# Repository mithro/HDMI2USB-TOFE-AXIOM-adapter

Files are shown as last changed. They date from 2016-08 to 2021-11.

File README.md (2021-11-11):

# TOFE to AXIOM Adapter

This repository contains a board for adapting the
[TOFE interface](https://tofe.io/) to the interface used by the
[plugin modules for the AXIOM Beta](https://wiki.apertus.org/index.php/AXIOM_Beta/AXIOM_Beta_Hardware#Plugin_Modules).

These adapter boards are **transparent** to the TOFE bus and have identical
schematics, only the PCB design differs.

Any **passive** PCI-Express adapter or riser which meets the PCI-Express
specification should be also compatible with the TOFE interface (but the
reverse is not necessarily true).

For more information on;
 * [The TOFE interface, see the HDMI2USB website](http://hdmi2usb.tv/tofe).
 * [The AXIOM interface, see the AXIOM wiki](https://wiki.apertus.org/index.php/AXIOM_Beta)
 * KiCad software, see [KiCad website](http://kicad.org/).

## Editing

Download with
```
git clone git+ssh://git@github.com/mithro/HDMI2USB-TOFE-AXIOM-Adapter.git --recursive
```

The designs in this repository was made using [KiCad](http://www.kicad.org/)
version **4.0.2 BZR 6225**
([the current stable version of KiCad](http://kicad.org/download/)).

## License

This work is copyright TimVideos.us Developers 2015 and licensed under a
Creative Commons Attribution-ShareAlike 4.0 International License.

You should have received a copy of the license along with this
work.  If not, see <http://creativecommons.org/licenses/by-sa/4.0/>.



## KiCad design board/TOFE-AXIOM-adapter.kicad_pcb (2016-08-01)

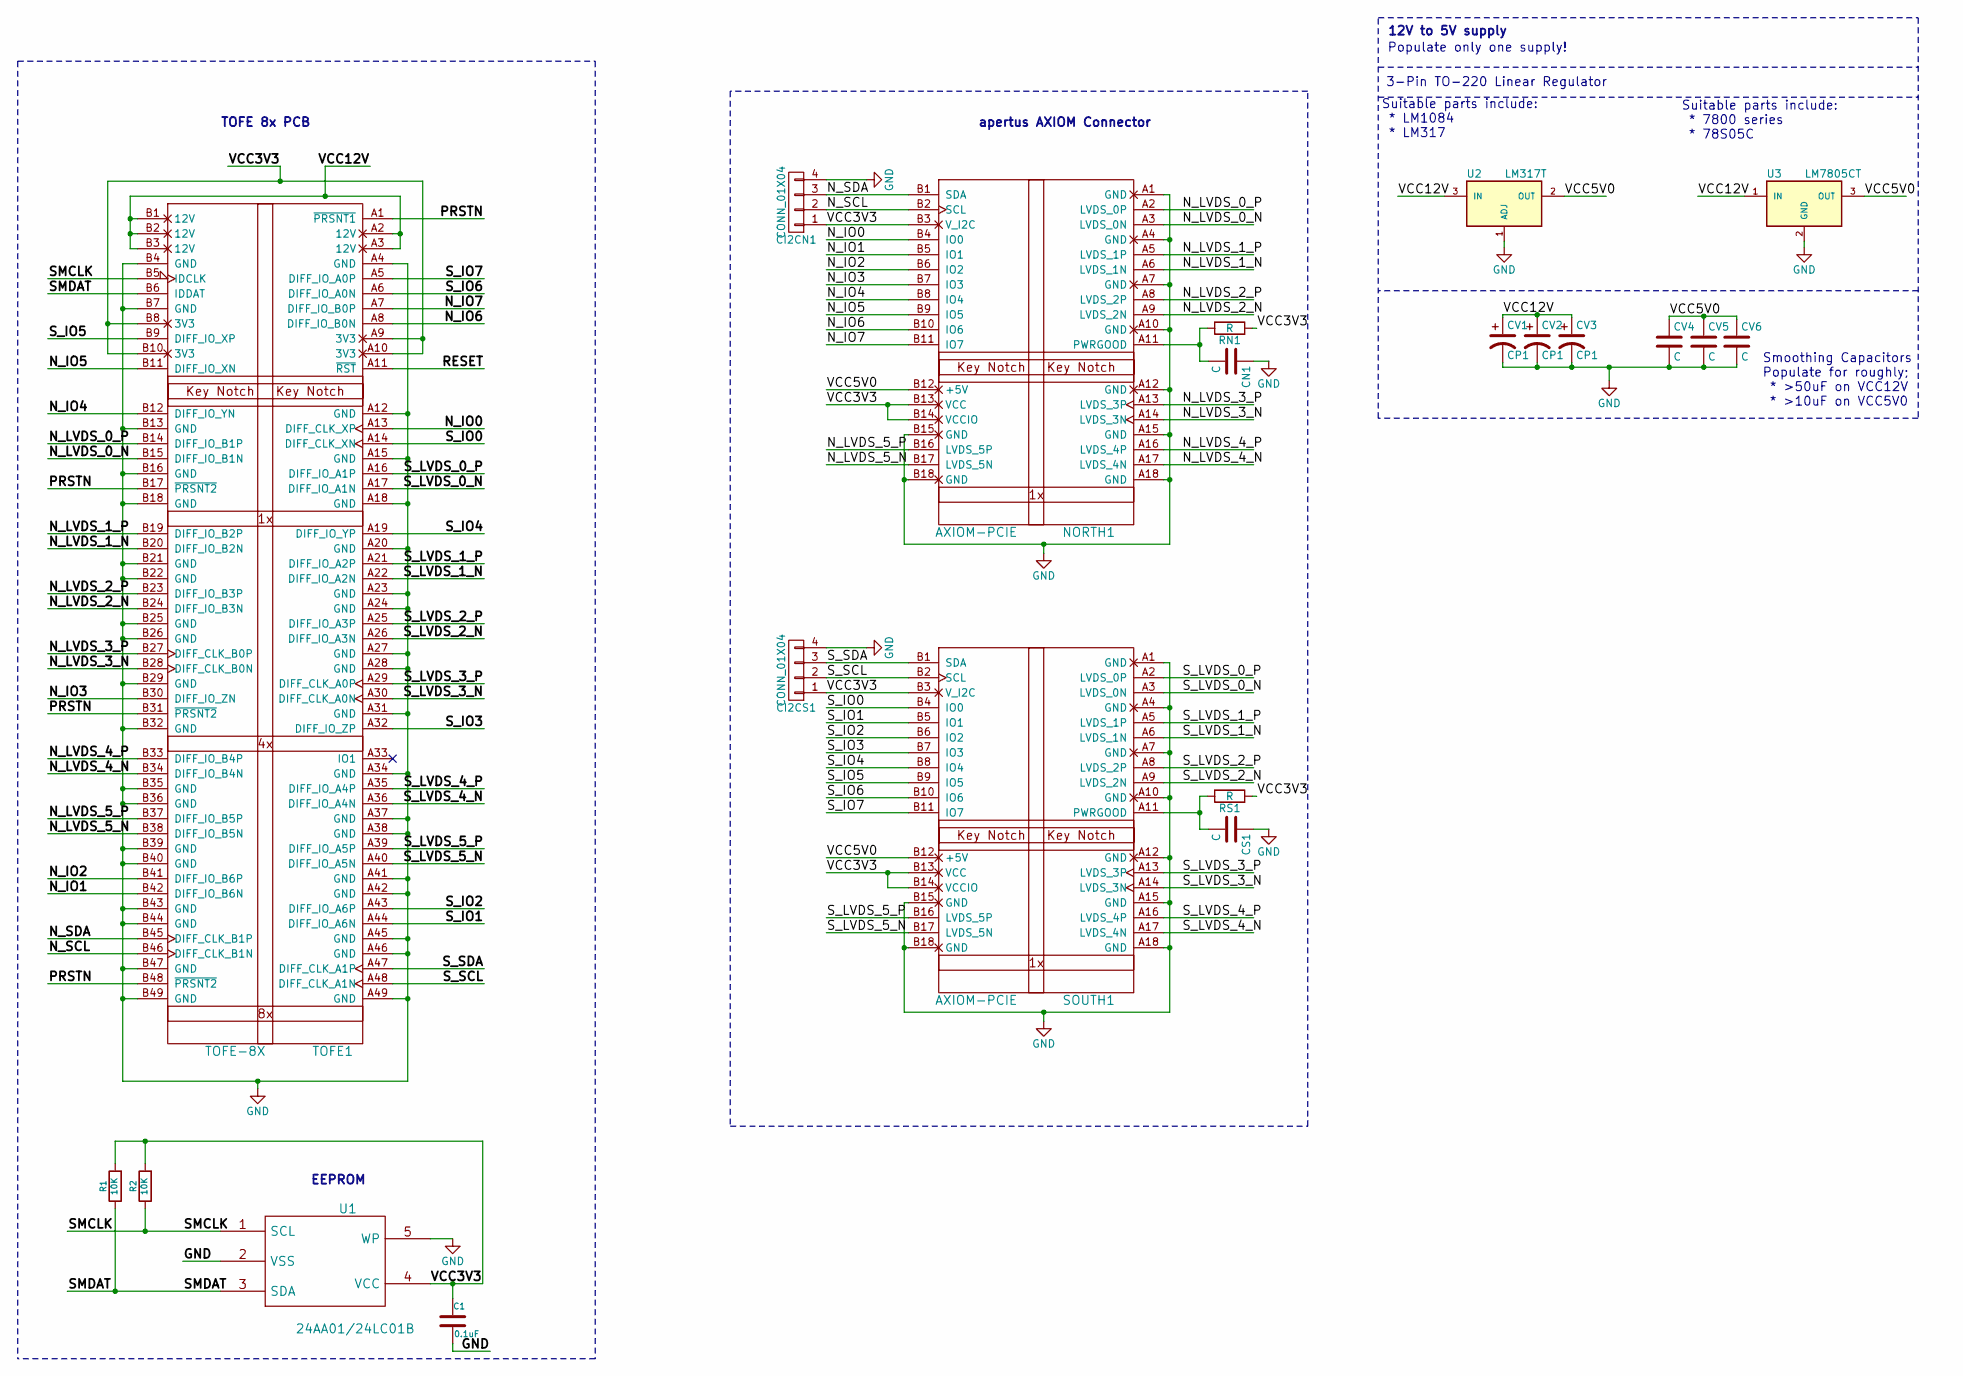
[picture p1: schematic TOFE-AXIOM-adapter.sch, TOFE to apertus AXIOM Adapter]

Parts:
C1: 0.1uF; C_1206_HandSoldering
CI2CN1, CI2CS1: CONN_01X04; Pin_Header_Straight_1x04
CN1: C; C_1206_HandSoldering
CS1: C; C_1206_HandSoldering
CV1, CV2, CV3: CP1; SMD-1206_Pol
CV4, CV5, CV6: C; C_1206_HandSoldering
NORTH1: AXIOM-PCIE; pci-x_conn-x1
R1, R2: 10K; R_0603_HandSoldering
RN1: R; R_0603_HandSoldering
RS1: R; R_0603_HandSoldering
SOUTH1: AXIOM-PCIE; pci-x_conn-x1
TOFE1: TOFE-8X; TOFE_8X_Pins
U1: 24AA01/24LC01B; SOT-23-5
U2: LM317T
U3: LM7805CT

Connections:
/N_IO0: NORTH1.B4 (IO0), TOFE1.A13 (DIFF_CLK_XP)
/N_IO1: NORTH1.B5 (IO1), TOFE1.B42 (DIFF_IO_B6N)
/N_IO2: NORTH1.B6 (IO2), TOFE1.B41 (DIFF_IO_B6P)
/N_IO3: NORTH1.B7 (IO3), TOFE1.B30 (DIFF_IO_ZN)
/N_IO4: NORTH1.B8 (IO4), TOFE1.B12 (DIFF_IO_YN)
/N_IO5: NORTH1.B9 (IO5), TOFE1.B11 (DIFF_IO_XN)
/N_IO6: NORTH1.B10 (IO6), TOFE1.A8 (DIFF_IO_B0N)
/N_IO7: NORTH1.B11 (IO7), TOFE1.A7 (DIFF_IO_B0P)
/N_LVDS_0_N: NORTH1.A3 (LVDS_0N), TOFE1.B15 (DIFF_IO_B1N)
/N_LVDS_0_P: NORTH1.A2 (LVDS_0P), TOFE1.B14 (DIFF_IO_B1P)
/N_LVDS_1_N: NORTH1.A6 (LVDS_1N), TOFE1.B20 (DIFF_IO_B2N)
/N_LVDS_1_P: NORTH1.A5 (LVDS_1P), TOFE1.B19 (DIFF_IO_B2P)
/N_LVDS_2_N: NORTH1.A9 (LVDS_2N), TOFE1.B24 (DIFF_IO_B3N)
/N_LVDS_2_P: NORTH1.A8 (LVDS_2P), TOFE1.B23 (DIFF_IO_B3P)
/N_LVDS_3_N: NORTH1.A14 (LVDS_3N), TOFE1.B28 (DIFF_CLK_B0N)
/N_LVDS_3_P: NORTH1.A13 (LVDS_3P), TOFE1.B27 (DIFF_CLK_B0P)
/N_LVDS_4_N: NORTH1.A17 (LVDS_4N), TOFE1.B34 (DIFF_IO_B4N)
/N_LVDS_4_P: NORTH1.A16 (LVDS_4P), TOFE1.B33 (DIFF_IO_B4P)
/N_LVDS_5_N: NORTH1.B17 (LVDS_5N), TOFE1.B38 (DIFF_IO_B5N)
/N_LVDS_5_P: NORTH1.B16 (LVDS_5P), TOFE1.B37 (DIFF_IO_B5P)
/N_SCL: CI2CN1.2, NORTH1.B2 (SCL), TOFE1.B46 (DIFF_CLK_B1N)
/N_SDA: CI2CN1.3, NORTH1.B1 (SDA), TOFE1.B45 (DIFF_CLK_B1P)
/PRSTN: TOFE1.A1 (~PRSNT1), TOFE1.B17 (~PRSNT2), TOFE1.B31 (~PRSNT2), TOFE1.B48 (~PRSNT2)
/RESET: TOFE1.A11 (~RST)
/SMCLK: R2.1, TOFE1.B5 (IDCLK), U1.1 (SCL)
/SMDAT: R1.1, TOFE1.B6 (IDDAT), U1.3 (SDA)
/S_IO0: SOUTH1.B4 (IO0), TOFE1.A14 (DIFF_CLK_XN)
/S_IO1: SOUTH1.B5 (IO1), TOFE1.A44 (DIFF_IO_A6N)
/S_IO2: SOUTH1.B6 (IO2), TOFE1.A43 (DIFF_IO_A6P)
/S_IO3: SOUTH1.B7 (IO3), TOFE1.A32 (DIFF_IO_ZP)
/S_IO4: SOUTH1.B8 (IO4), TOFE1.A19 (DIFF_IO_YP)
/S_IO5: SOUTH1.B9 (IO5), TOFE1.B9 (DIFF_IO_XP)
/S_IO6: SOUTH1.B10 (IO6), TOFE1.A6 (DIFF_IO_A0N)
/S_IO7: SOUTH1.B11 (IO7), TOFE1.A5 (DIFF_IO_A0P)
/S_LVDS_0_N: SOUTH1.A3 (LVDS_0N), TOFE1.A17 (DIFF_IO_A1N)
/S_LVDS_0_P: SOUTH1.A2 (LVDS_0P), TOFE1.A16 (DIFF_IO_A1P)
/S_LVDS_1_N: SOUTH1.A6 (LVDS_1N), TOFE1.A22 (DIFF_IO_A2N)
/S_LVDS_1_P: SOUTH1.A5 (LVDS_1P), TOFE1.A21 (DIFF_IO_A2P)
/S_LVDS_2_N: SOUTH1.A9 (LVDS_2N), TOFE1.A26 (DIFF_IO_A3N)
/S_LVDS_2_P: SOUTH1.A8 (LVDS_2P), TOFE1.A25 (DIFF_IO_A3P)
/S_LVDS_3_N: SOUTH1.A14 (LVDS_3N), TOFE1.A30 (DIFF_CLK_A0N)
/S_LVDS_3_P: SOUTH1.A13 (LVDS_3P), TOFE1.A29 (DIFF_CLK_A0P)
/S_LVDS_4_N: SOUTH1.A17 (LVDS_4N), TOFE1.A36 (DIFF_IO_A4N)
/S_LVDS_4_P: SOUTH1.A16 (LVDS_4P), TOFE1.A35 (DIFF_IO_A4P)
/S_LVDS_5_N: SOUTH1.B17 (LVDS_5N), TOFE1.A40 (DIFF_IO_A5N)
/S_LVDS_5_P: SOUTH1.B16 (LVDS_5P), TOFE1.A39 (DIFF_IO_A5P)
/S_SCL: CI2CS1.2, SOUTH1.B2 (SCL), TOFE1.A48 (DIFF_CLK_A1N)
/S_SDA: CI2CS1.3, SOUTH1.B1 (SDA), TOFE1.A47 (DIFF_CLK_A1P)
/VCC3V3: C1.1, CI2CN1.1, CI2CS1.1, NORTH1.B3 (V_I2C), NORTH1.B13 (VCC), NORTH1.B14 (VCCIO), R1.2, R2.2, RN1.1, RS1.1, SOUTH1.B3 (V_I2C), SOUTH1.B13 (VCC), SOUTH1.B14 (VCCIO), TOFE1.A9 (3V3), TOFE1.A10 (3V3), TOFE1.B8 (3V3), TOFE1.B10 (3V3), U1.4 (VCC)
/VCC5V0: CV4.1, CV5.1, CV6.1, NORTH1.B12 (+5V), SOUTH1.B12 (+5V), U2.2 (OUT), U3.3 (OUT)
/VCC12V: CV1.1, CV2.1, CV3.1, TOFE1.A2 (12V), TOFE1.A3 (12V), TOFE1.B1 (12V), TOFE1.B2 (12V), TOFE1.B3 (12V), U2.3 (IN), U3.1 (IN)
GND: C1.2, CI2CN1.4, CI2CS1.4, CN1.1, CS1.1, CV1.2, CV2.2, CV3.2, CV4.2, CV5.2, CV6.2, NORTH1.A1 (GND), NORTH1.A4 (GND), NORTH1.A7 (GND), NORTH1.A10 (GND), NORTH1.A12 (GND), NORTH1.A15 (GND), NORTH1.A18 (GND), NORTH1.B15 (GND), NORTH1.B18 (GND), SOUTH1.A1 (GND), SOUTH1.A4 (GND), SOUTH1.A7 (GND), SOUTH1.A10 (GND), SOUTH1.A12 (GND), SOUTH1.A15 (GND), SOUTH1.A18 (GND), SOUTH1.B15 (GND), SOUTH1.B18 (GND), TOFE1.A4 (GND), TOFE1.A12 (GND), TOFE1.A15 (GND), TOFE1.A18 (GND), TOFE1.A20 (GND), TOFE1.A23 (GND), TOFE1.A24 (GND), TOFE1.A27 (GND), TOFE1.A28 (GND), TOFE1.A31 (GND), TOFE1.A34 (GND), TOFE1.A37 (GND), TOFE1.A38 (GND), TOFE1.A41 (GND), TOFE1.A42 (GND), TOFE1.A45 (GND), TOFE1.A46 (GND), TOFE1.A49 (GND), TOFE1.B4 (GND), TOFE1.B7 (GND), TOFE1.B13 (GND), TOFE1.B16 (GND), TOFE1.B18 (GND), TOFE1.B21 (GND), TOFE1.B22 (GND), TOFE1.B25 (GND), TOFE1.B26 (GND), TOFE1.B29 (GND), TOFE1.B32 (GND), TOFE1.B35 (GND), TOFE1.B36 (GND), TOFE1.B39 (GND), TOFE1.B40 (GND), TOFE1.B43 (GND), TOFE1.B44 (GND), TOFE1.B47 (GND), TOFE1.B49 (GND), U1.2 (VSS), U1.5 (WP), U2.1 (ADJ), U3.2 (GND)
unnamed: CN1.2, NORTH1.A11 (PWRGOOD), RN1.2
unnamed: CS1.2, RS1.2, SOUTH1.A11 (PWRGOOD)

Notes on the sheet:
TOFE 8x PCB
apertus AXIOM Connector
EEPROM
12V to 5V supply
Populate only one supply!
3-Pin TO-220 Linear Regulator
Suitable parts include: * LM1084 * LM317
Suitable parts include: * 7800 series * 78S05C
Smoothing Capacitors Populate for roughly; * >50uF on VCC12V * >10uF on VCC5V0

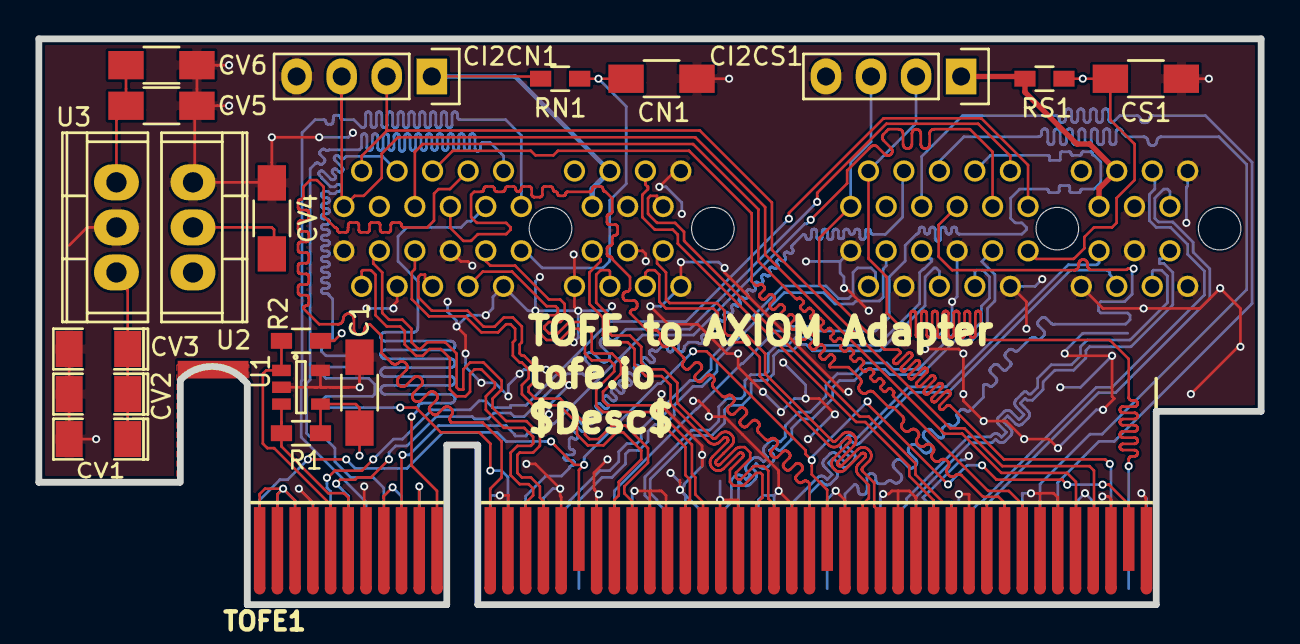
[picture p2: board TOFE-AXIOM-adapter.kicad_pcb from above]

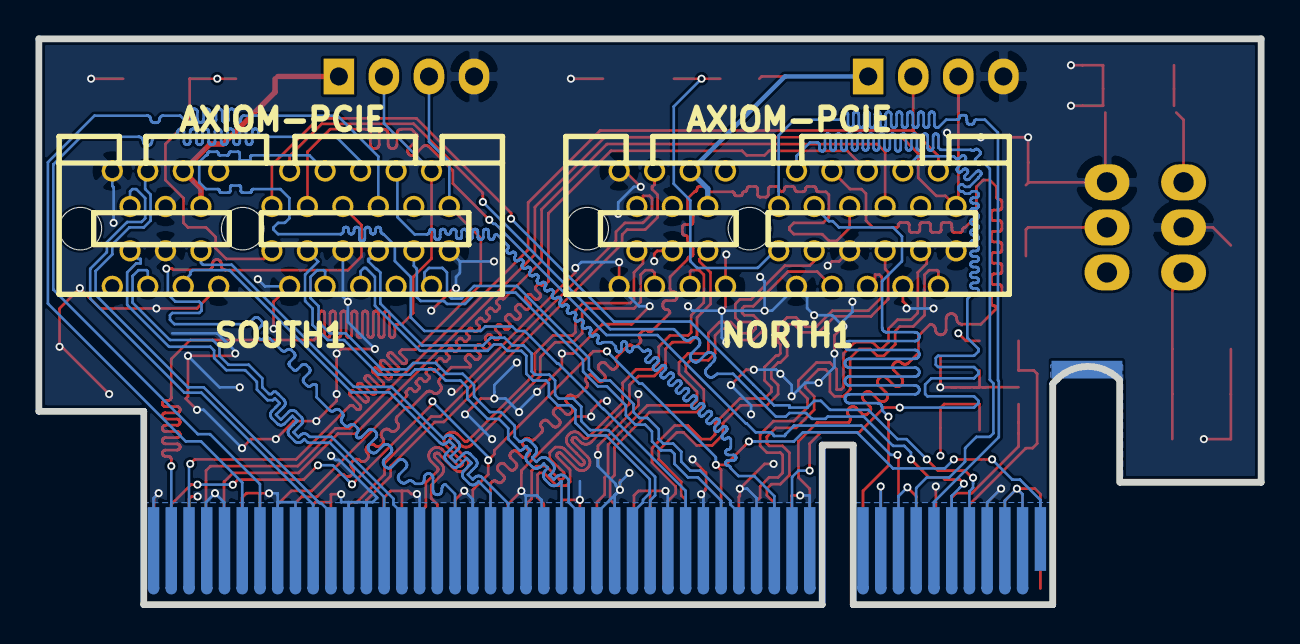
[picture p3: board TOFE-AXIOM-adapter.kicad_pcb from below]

Board: 4 copper layers, 68.9 x 31.9 mm, 21 parts (2 on the bottom side), 53 nets.

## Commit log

2016-03-18 Taking the TOFE left angle adapter as starting point.
    (Source from https://github.com/timvideos/HDMI2USB-TOFE-adapters-and-risers)
    [TOFE-AXIOM-adapter.kicad_pcb, TOFE-AXIOM-adapter.sch]
2016-03-18 Slowly working on the adapter.
    [TOFE-AXIOM-adapter.kicad_pcb, TOFE-AXIOM-adapter.sch]
2016-03-18 More work.
    [TOFE-AXIOM-adapter.sch]
2016-03-18 Starting work on the PCB.
    [TOFE-AXIOM-adapter.kicad_pcb]
2016-03-18 Import PCI-Express connectors.
    [TOFE-AXIOM-adapter.sch]
2016-03-18 Slowly getting there.
    [TOFE-AXIOM-adapter.kicad_pcb, TOFE-AXIOM-adapter.sch]
2016-03-18 Importing the ID EEPROM.
    [TOFE-AXIOM-adapter.sch]
2016-03-18 Associating footprints.
    [TOFE-AXIOM-adapter.sch]
2016-03-18 Fixing the diff pairs.
    [TOFE-AXIOM-adapter.sch]
2016-03-18 Remove most of the routing from the PCB.
    [TOFE-AXIOM-adapter.kicad_pcb]
2016-03-18 Actually fixing the diff pairs.
    [TOFE-AXIOM-adapter.sch]
2016-03-18 Slowly laying out the PCB.
    [TOFE-AXIOM-adapter.kicad_pcb, TOFE-AXIOM-adapter.sch]
2016-03-20 Working on routing.
    [TOFE-AXIOM-adapter.kicad_pcb]
2016-03-20 VCCIO set to 3V3
    [TOFE-AXIOM-adapter.sch]
2016-03-20 Adding the DRC rules from the apertus group for their board.
2016-03-20 Changing wires to match DRC.
    [TOFE-AXIOM-adapter.kicad_pcb]
2016-03-20 Small fix.
    [TOFE-AXIOM-adapter.kicad_pcb]
2016-03-21 Moving the kicad submodule forward.
2016-03-21 Converted to just the pins footprint.
    [TOFE-AXIOM-adapter.kicad_pcb, TOFE-AXIOM-adapter.sch]
2016-03-21 Lots of fix ups.
    [TOFE-AXIOM-adapter.kicad_pcb]
2016-03-21 Adding a boundry trace to make the push/shove stuff easier to work with.
    [TOFE-AXIOM-adapter.kicad_pcb]
2016-03-21 Adding debug header for I2C lines.
    [TOFE-AXIOM-adapter.sch]
2016-03-21 More routing.
    [TOFE-AXIOM-adapter.kicad_pcb]
2016-03-23 Adding 12V to 5V power supply.
    [TOFE-AXIOM-adapter.sch]
2016-03-23 Adding annotations and parts.
    [TOFE-AXIOM-adapter.sch]
2016-03-23 Adding more parts to the PCB.
    [TOFE-AXIOM-adapter.kicad_pcb]
2016-03-28 Fixed connector spacing to be 28.575 (rather then 28.500) spacing.
    [TOFE-AXIOM-adapter.kicad_pcb]
2016-03-28 Starting to get length matching checking working.
    [TOFE-AXIOM-adapter.kicad_pcb]
2016-03-28 Fixing the length matching requirements.
    [TOFE-AXIOM-adapter.kicad_pcb]
2016-04-07 Updates from Dejan Stevanovic.
    [TOFE-AXIOM-adapter.kicad_pcb, TOFE-AXIOM-adapter.sch]
2016-04-07 Clean up of diff pairs.
    [TOFE-AXIOM-adapter.kicad_pcb]
2016-05-23 Low speed I/O" are matched to be roughly 10mil.
    [TOFE-AXIOM-adapter.kicad_pcb]
2016-05-23 Small cleanup.
    [TOFE-AXIOM-adapter.kicad_pcb]
2016-05-23 Making all the lengths actually match.
    [TOFE-AXIOM-adapter.kicad_pcb]
2016-05-28 Fixing via requirements.
    [TOFE-AXIOM-adapter.kicad_pcb]
2016-05-28 Fixing via sizes.
    [TOFE-AXIOM-adapter.kicad_pcb]
2016-05-28 Loading the fixed TOFE-8X Pins part.
    [TOFE-AXIOM-adapter.kicad_pcb]
2016-05-28 Fixing DRC caused by wrong via size usage.
    [TOFE-AXIOM-adapter.kicad_pcb]
2016-05-28 Fixing more DRC errors.
    [TOFE-AXIOM-adapter.kicad_pcb]
2016-05-28 Make VCC names consistent.
    [TOFE-AXIOM-adapter.sch]
2016-05-28 Using the inner layer for VCC routing.
    [TOFE-AXIOM-adapter.kicad_pcb]
2016-05-28 Updating netlist and adding VCC polygons.
    [TOFE-AXIOM-adapter.kicad_pcb]
2016-05-28 More fixing power supply.
    [TOFE-AXIOM-adapter.sch]
2016-05-28 More power supply planes.
    [TOFE-AXIOM-adapter.kicad_pcb]
2016-05-28 More power fixes.
    [TOFE-AXIOM-adapter.kicad_pcb]
2016-05-28 More DRC fixing.
    [TOFE-AXIOM-adapter.kicad_pcb]
2016-06-01 Temp commit.
    [TOFE-AXIOM-adapter.kicad_pcb]
2016-07-03 Removing interesting extra name.
    [TOFE-AXIOM-adapter.sch]
2016-07-03 First drop from Phyllis.
    [TOFE-AXIOM-adapter.kicad_pcb]
2016-07-03 Fixing the EEPROM location in schematic.
    [TOFE-AXIOM-adapter.sch]
2016-07-03 Update for schematic changes.
    [TOFE-AXIOM-adapter.kicad_pcb]
2016-07-03 Setting VCCIO to VCC3V3.
    [TOFE-AXIOM-adapter.kicad_pcb, TOFE-AXIOM-adapter.sch]
2016-07-03 Fix pullup PWRGOOD circuit.
    [TOFE-AXIOM-adapter.kicad_pcb, TOFE-AXIOM-adapter.sch]
2016-07-08 Update number 3 from Phyllis.
    [TOFE-AXIOM-adapter.kicad_pcb, TOFE-AXIOM-adapter.sch]
2016-07-08 Adding fill zones on front / back.
    [TOFE-AXIOM-adapter.kicad_pcb]
2016-07-24 Update number 4 from Phyllis.
    [TOFE-AXIOM-adapter.kicad_pcb]
2016-08-01 Adding a release script.
    [TOFE-AXIOM-adapter.kicad_pcb]
2016-08-01 Adding output gerber directory.
2016-08-01 Creating gerbers v0.2-1-g36b3ea2 for TOFE-AXIOM-adapter
    [TOFE-AXIOM-adapter-CuBottom.gbl, TOFE-AXIOM-adapter-CuTop.gtl, TOFE-AXIOM-adapter-EdgeCuts.gm1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]
2016-08-01 Remove text on the back.
    [TOFE-AXIOM-adapter.kicad_pcb]
2021-11-10 Update README.md
    https://forum.kicad.info/t/warning-avoid-all-links-to-kicad-pcb-org-use-kicad-org/31521

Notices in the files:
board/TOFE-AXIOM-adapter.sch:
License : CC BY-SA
